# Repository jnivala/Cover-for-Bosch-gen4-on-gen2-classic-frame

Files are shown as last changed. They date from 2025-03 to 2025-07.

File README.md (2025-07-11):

# Motor cover for an ebike with a Bosch gen4 motor retrofitted to a gen2 classic frame
[Cobee](https://www.emtbforums.com/members/cobee.29868/) sells adapters that allow you to install a Bosch gen4 motor to an ebike that was factory fitted with a gen2 Performance Line or Performance Line CX motor (see [this thread](https://www.emtbforums.com/threads/anyone-ever-replaced-a-cx-gen-2-for-the-new-gen-4.20513/)).

The adapters are bolt-on and work well. The original motor cover is not compatible with the retrofitted gen4 motor. This repository tries to solve the "cover issue" for those bikes that had the standard Bosch egg-shaped cover. It looks like this with gen2 motor:

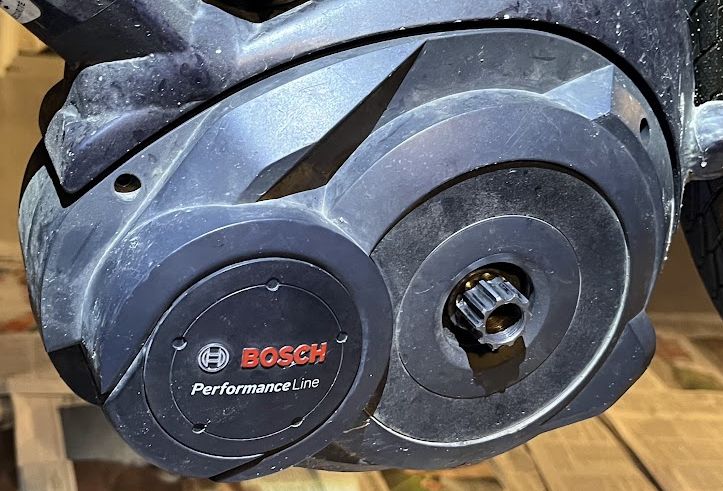
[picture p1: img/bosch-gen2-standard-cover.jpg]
Bosch gen2 standard cover


Covers for gen4:

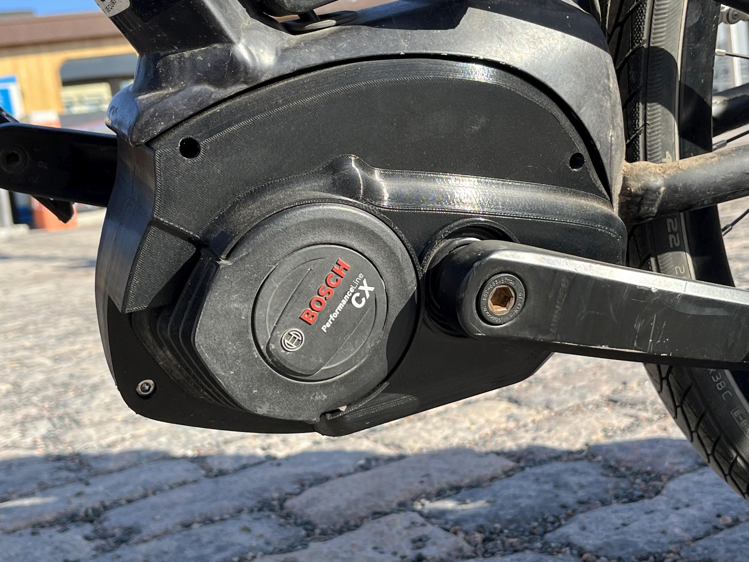
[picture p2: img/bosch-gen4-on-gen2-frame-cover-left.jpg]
Cover gen4 left Cover gen4 on gen2 frame left


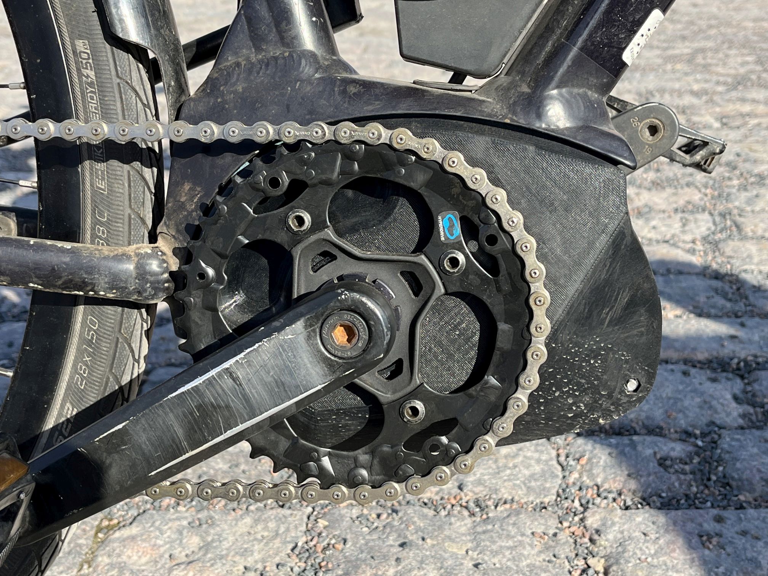
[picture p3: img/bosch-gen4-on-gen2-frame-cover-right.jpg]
Cover gen4 right Cover gen4 on gen2 frame right


The right side of the engine was too complicated to deal with so I covered it completely. That's why the left side has a downward hole in the front for airflow. On the right side there is a slot to allow easier installation of spider bolts. Left and right side are joined with four screws. Upper two are standard Bosch gen2 case screws. Lower two are M5 (hex screw with round head). In the bottom there are holes to allow water to exit like in standard gen2 cover.

The right side top could be raised a bit, perhaps 1 mm. It seems the lower seam does not close perfectly. I did not examine that further. Anyway, the case seems to work well enough.

Repository includes STL files and the Autodesk Fusion 360 design file. Fusion 360 is free for personal use. The project was my first with Fusion 360. The project timeline could be cleaner, constraints used rather than fixing items, etc.

The Fusion 360 file contains reference scan as a mesh. The cover was designed around it. Scan was produced using RealityScan on a phone and cleaned with MeshMixer and Meshlab.

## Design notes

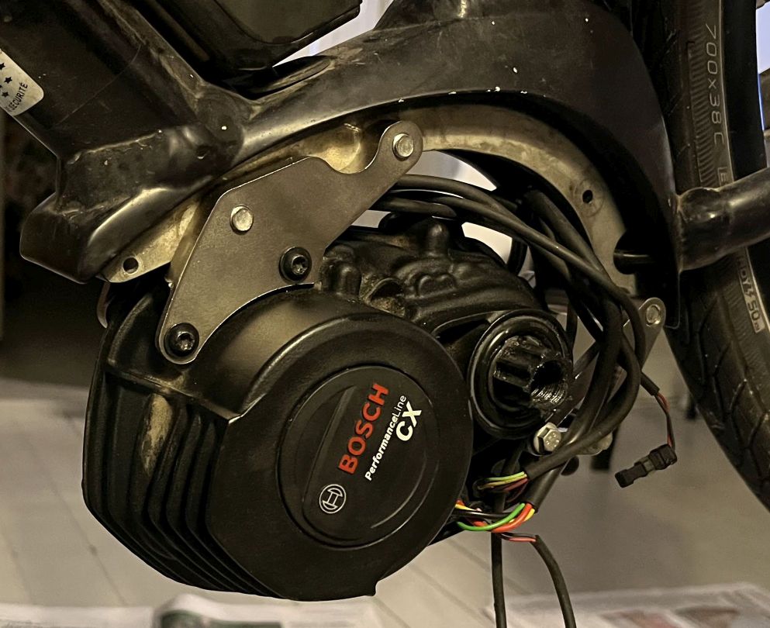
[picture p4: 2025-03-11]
img/bosch-gen4-open-left.jpg

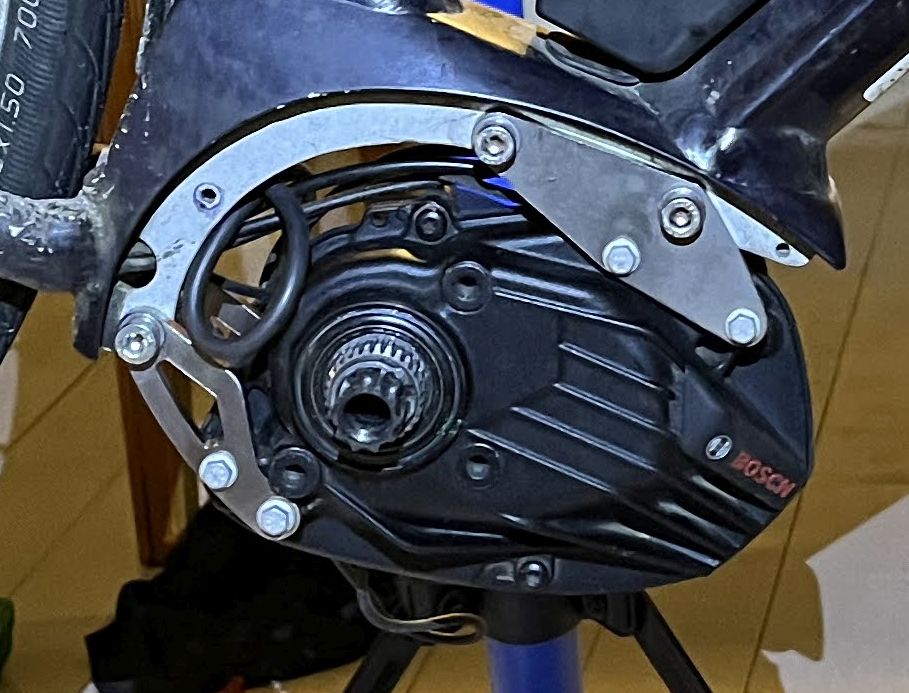
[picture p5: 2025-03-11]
img/bosch-gen4-open-right.jpg

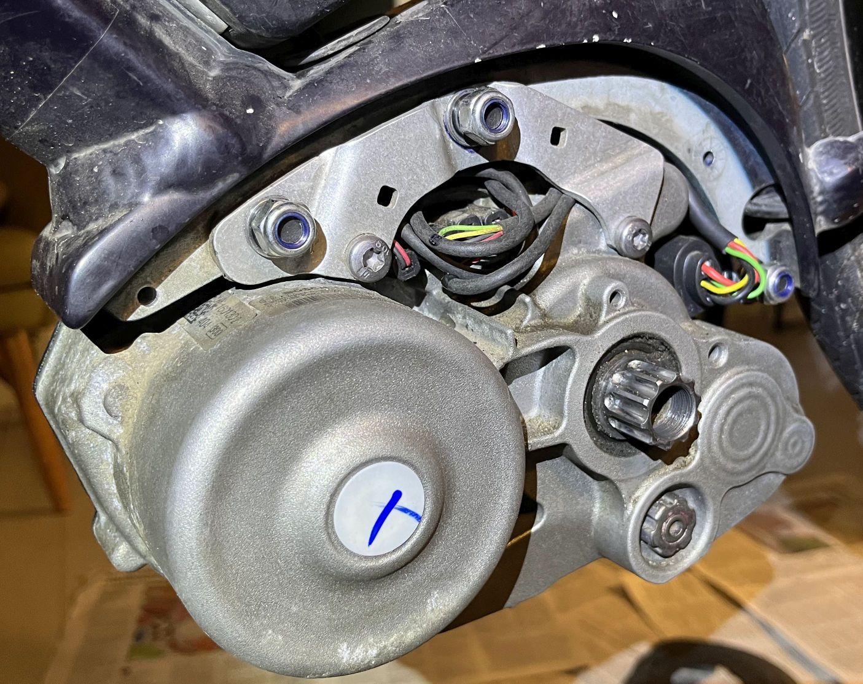
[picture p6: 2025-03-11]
img/bosch-gen2-open-left.jpg

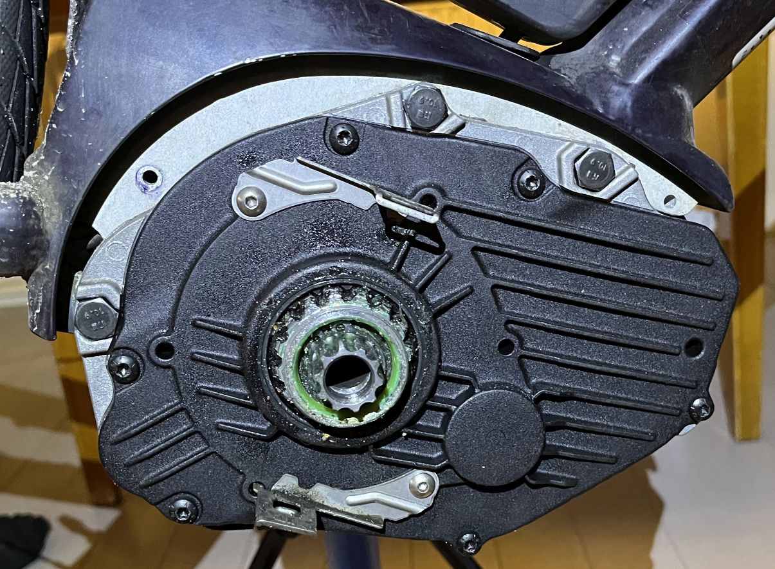
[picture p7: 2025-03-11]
img/bosch-gen2-open-right.jpg

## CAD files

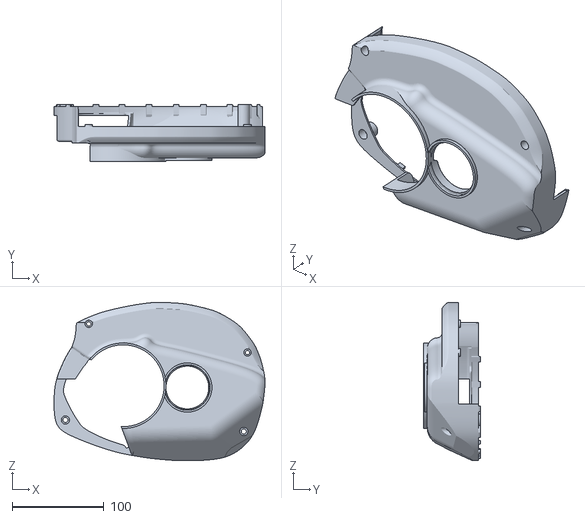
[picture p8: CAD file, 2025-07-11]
Left cover for Bosch gen4 on gen2 classic frame.stl
229.7 x 62.0 x 172.5

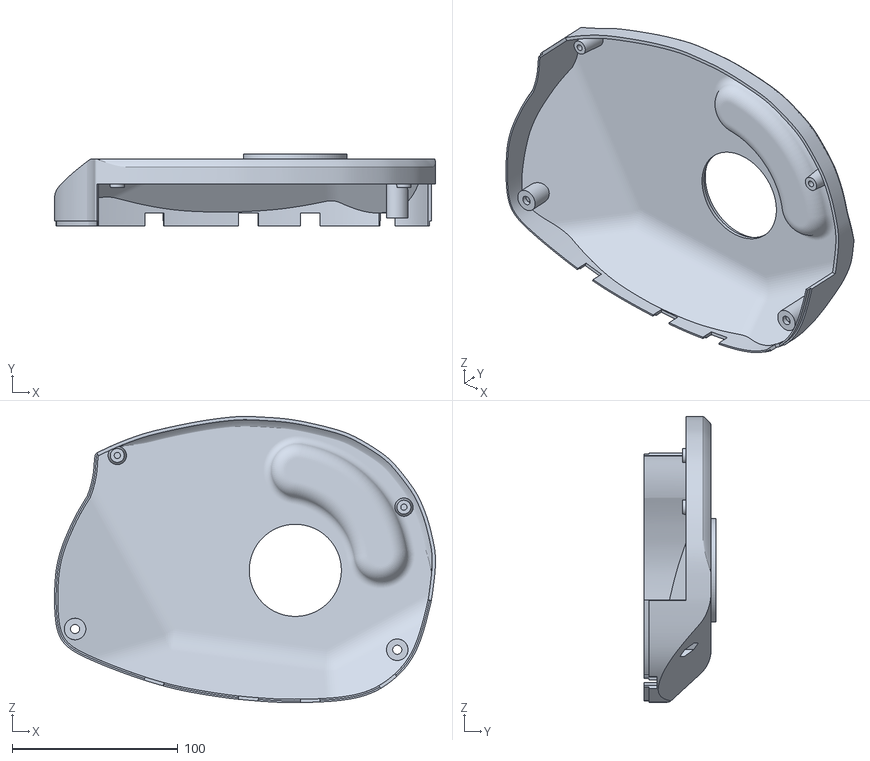
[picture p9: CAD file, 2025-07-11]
Right cover for Bosch gen4 on gen2 classic frame.stl
229.7 x 43.5 x 172.5

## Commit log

2025-03-11 Merge meature/import to main (#1)
    * Update README.md
    * Update README.md
    * Update README.md
    * Update README.md
    * Create bosch-gen2-standard-cover.jpg
    * Update README.md
    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
    [Left cover for Bosch gen4 on gen2 classic frame.stl, Right cover for Bosch gen4 on gen2 classic frame.stl]
2025-07-11 Feature/top fillet (#2)
    * Added fillet to top on both sides to help water drain better
    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
    [Left cover for Bosch gen4 on gen2 classic frame.stl, Right cover for Bosch gen4 on gen2 classic frame.stl]
